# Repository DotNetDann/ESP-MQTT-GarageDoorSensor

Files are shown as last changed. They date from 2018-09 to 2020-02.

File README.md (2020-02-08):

# ESP8266 MQTT GarageDoorSensor and Temperture HomeAssistant
This project allows for up to  three "dumb" garage door openers to be controlled (open/close) and report garage door status (open/closed/occupied) via MQTT. In addition if you can also monitor the Temperture and Humidity within your garage to over MQTT as well.

The code covered in this repository utilizes [Home Assistant's MQTT Cover Component](https://www.home-assistant.io/components/cover.mqtt/) and uses an ESP8266 microcontroller. There is a sample configuration in the repository

Inspiration for this comes from GarHAge and OpenGarage. The Temp and Humidity code for a DHT22 from GarHage, and now it morphed to change to NewPing for the ultrasonic HC-SR04 due to the inconsitant reading using the Ultrasonic library with the HC-SCR04 I aquired from china.

**NOTE:** I am currrently only using this with one garage door, to enable for 2 or 3, just enable the use to true in the auth.h file you create

#### Supported Features Include
- Report status on up to 3 garage doors
- Report information on Temp and Humidity
- Ability to Select Celius or Fahrenheit for Temp
- Web page for status of Garage Doors and Temperature
- Events and status sent via MQTT
- MQTT commands to toggle relays to open/close the garage doors
- Over-the-Air (OTA) Upload from the ArduinoIDE!

#### OTA Uploading
This code also supports remote uploading to the ESP8266 using Arduino's OTA library. To utilize this, you'll need to first upload the sketch using the traditional USB method. However, if you need to update your code after that, your WIFI-connected ESP chip should show up as an option under Tools -> Port -> 'HostName'at your.ip.address.xxx. 

More information on OTA uploading can be found [here](http://esp8266.github.io/Arduino/versions/2.0.0/doc/ota_updates/ota_updates.html). 

#### Parts List
- [NodeMCU](https://www.amazon.com/HiLetgo-Version-NodeMCU-Internet-Development/dp/B010O1G1ES/)
- [1-3 x HC-SR04 Ultrasonic Sensors](https://au.element14.com/mcm/83-17989/hc-sr04-ultrasonic-sensor-for/dp/2801408?ost=HC-SR04) Depending on how many Doors you will monitor
- [5V 4 Channel Relay Board](https://www.ebay.com./sch/i.html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) If Controling 2 or More Garage Doors this is the best choice
- Otherwise buy a Single Relay for a singe Door
	[5V 1 Channel Relay Board](https://www.ebay.com./sch/i.html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)

#### Wiring Diagram
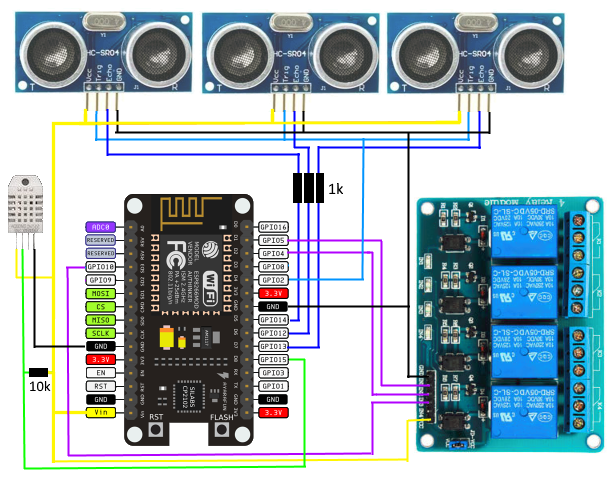
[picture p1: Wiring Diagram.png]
Wiring Diagram


#### Web page
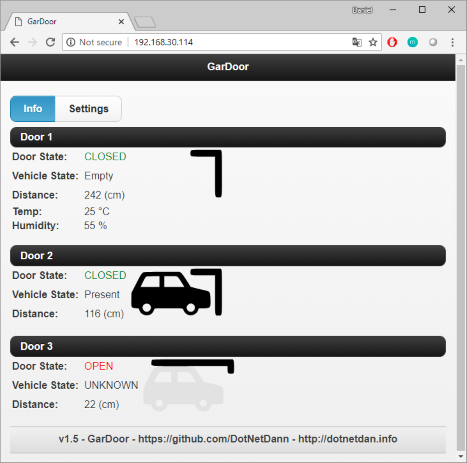
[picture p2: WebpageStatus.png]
Webpage Status


#### Completed Project
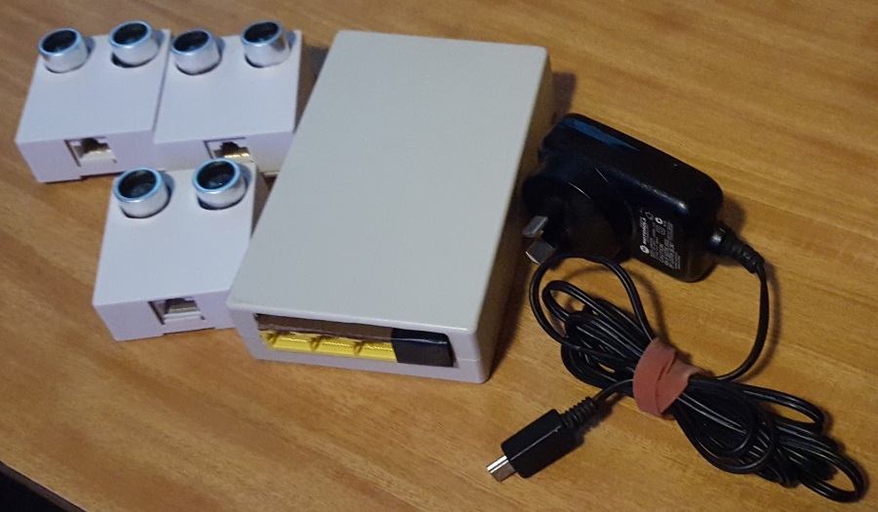
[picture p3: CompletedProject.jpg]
Completed Project

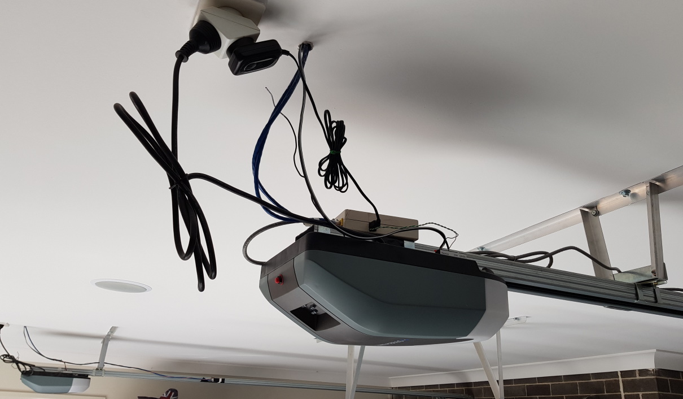
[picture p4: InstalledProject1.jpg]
Installed

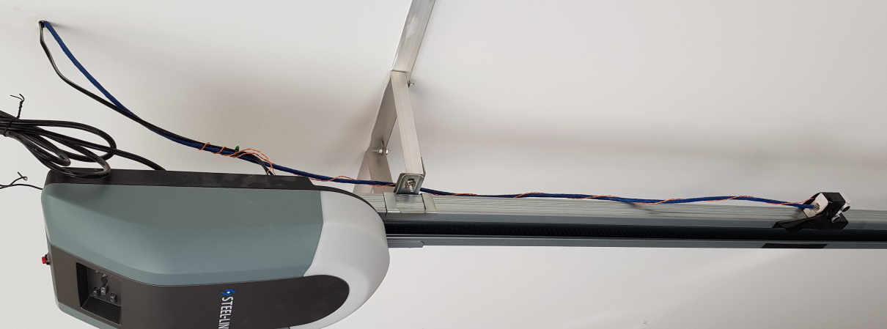
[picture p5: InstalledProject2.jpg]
Installed


I have also made a stl bracket to hold it to the rail 

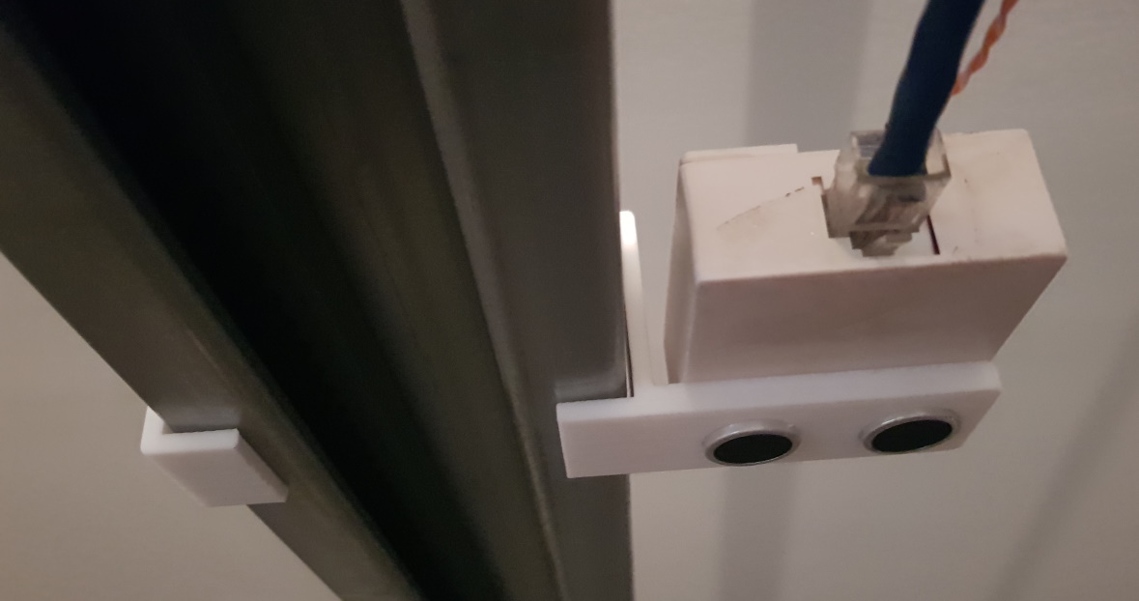
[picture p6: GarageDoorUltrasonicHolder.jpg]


#### Sample MQTT commands
Listen to MQTT commands
> mosquitto_sub -h 172.17.0.1 -t '#'

Open the second garage door
> mosquitto_pub -h 172.17.0.1 -t GarDoor/2/action -m "OPEN"

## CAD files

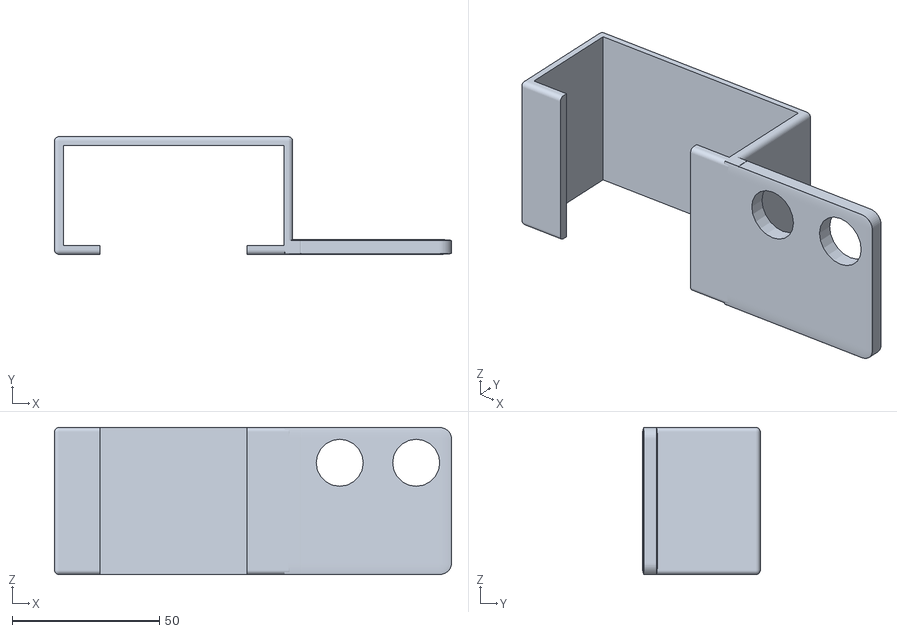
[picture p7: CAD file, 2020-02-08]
GarageDoorUltrasonicHolder.stl
135.0 x 40.0 x 50.0

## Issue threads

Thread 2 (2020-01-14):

Wiring Diagram

gdc2john, 2020-01-14:
HI Dan, I am setting up your controller but I notice that the wiring diagram does not line
up with the Auth.h file the outputs etc are different.
Are the correct one to use the ones in the auth.h file? which I guess must be correct

Cheer John

gdc2john, 2020-01-14:
I also get the an error when compiling the files in Arduinio IDE the eror is in web.h I have included a screen shot for your info
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

gdc2john, 2020-01-15:
Hi,, I solved the second problem, My Auth.h file must have had a corruption on download, a new download fixed it. Should have tried this before posting the error, sorry.

Closed 2020-01-19.

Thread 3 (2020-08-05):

I keep getting an error and cannot get this to work.

cbatten01, 2020-08-05:
I have tried everything and keep getting this error.  I think the codes were changed but the wiring diagram was not.  I am new to this.

ets Jan  8 2013,rst cause:4, boot mode:(3,6)

wdt reset
load 0x4010f000, len 3584, room 16
tail 0
chksum 0xb0
csum 0xb0
v5d3af165
~ld
Starting...

DotNetDann, 2020-08-06:
That message is your ESP chip resetting due to the code loop not running.
(Watch dog timer is resetting the board)
All pinouts are set by you in the auth.h file. Check these.
I would disable all but one garage door first and try that and then
re-enable others as you go.

I have actually moved off this and onto ESPHome
If you are starting out then this may be more friendly.

I have my config for esphome here -
https://github.com/DotNetDann/esphome-config/blob/master/garage_door.yaml

I hope that helps

Dan

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

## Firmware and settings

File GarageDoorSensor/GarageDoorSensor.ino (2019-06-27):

/*
  To use this code you will need the following dependencies:

  - Support for the ESP8266 boards.
        - You can add it to the board manager by going to File -> Preference and pasting http://arduino.esp8266.com/stable/package_esp8266com_index.json into the Additional Board Managers URL field.
        - Next, download the ESP8266 dependencies by going to Tools -> Board -> Board Manager and searching for ESP8266 and installing it.

  - You will also need to download the follow libraries by going to Sketch -> Include Libraries -> Manage Libraries
      - NewPing
      - PubSubClient
      - ArduinoJSON

  - Another like project https://hackaday.io/project/25090/instructions
  - Where this code was forked from https://github.com/DotNetDann/ESP-MQTT-GarageDoorSensor
*/

// 1.8 Change pins and small clean
// 1.7 Add ability to only close garage doors
// 1.6 Add diagnose infomation on distances
// 1.4 Changes to use NewPing
// 1.3 adds DHT Sensor for Temp and Humidty

// ------------------------------
// ---- all config in auth.h ----
// ------------------------------
#define VERSION F("v1.8 - GarDoor - https://github.com/DotNetDann - http://dotnetdan.info")

#include <ArduinoJson.h> // Benoit Blanchon
#include <ESP8266WiFi.h>
#include <ESP8266WebServer.h>
#include <ESP8266HTTPClient.h>
#include <PubSubClient.h> // Nick O'Leary
#include <NewPing.h> // Tim Eckel
#include <ArduinoOTA.h>
#include <DHT.h> // Adafruit
#include <Adafruit_Sensor.h> // Adafruit Unified Sensor
#include "auth.h"

#define DOOR_UNKNOWN         0x00
#define DOOR_OPENED          0x01
#define DOOR_CLOSEDNOCAR     0x02
#define DOOR_CLOSEDWITHCAR   0x03
#define SONAR_NUM 3      // Number of sensors.


/**************************************** GLOBALS ***************************************/
const int BUFFER_SIZE = JSON_OBJECT_SIZE(10);
#define MQTT_MAX_PACKET_SIZE 512

const int door_numValues = 10;
int door1_lastDistanceValues[door_numValues];
int door2_lastDistanceValues[door_numValues];
int door3_lastDistanceValues[door_numValues];
int door1_lastDistanceValue = 0;
int door2_lastDistanceValue = 0;
int door3_lastDistanceValue = 0;

char* birthMessage = "online";
const char* lwtMessage = "offline";

const unsigned long dht_publish_interval_s = DHT_PUBLISH_INTERVAL;
unsigned long dht_lastReadTime = -1000;

/******************************** GLOBAL OBJECTS *******************************/

NewPing sonar[SONAR_NUM] = {   // Sensor object array.
  NewPing(DOOR_TRIG_PIN, DOOR1_ECHO_PIN, ULTRASONIC_MAX_DISTANCE), // Each sensor's trigger pin, echo pin, and max distance to ping. 0-2
  NewPing(DOOR_TRIG_PIN, DOOR2_ECHO_PIN, ULTRASONIC_MAX_DISTANCE), 
  NewPing(DOOR_TRIG_PIN, DOOR3_ECHO_PIN, ULTRASONIC_MAX_DISTANCE)
};

WiFiClient espClient;
PubSubClient client(espClient);
ESP8266WebServer server(80);
DHT dht(DHT_PIN, DHT_TYPE);

// Get the state of the garage based upon the sensor distance
byte getState(int distance)
{
  if (distance <= 1) {
    return DOOR_UNKNOWN; // Should not ever be this close. Probably an error
  } else if (distance <= ULTRASONIC_DIST_MAX_OPEN) {
    return DOOR_OPENED;
  } else if (distance <= ULTRASONIC_DIST_MAX_CAR) {
    return DOOR_CLOSEDWITHCAR;
  } else {
    return DOOR_CLOSEDNOCAR;
  }
}

#include "web.h"

/********************************** START SETUP *****************************************/
void setup() {
  pinMode(LED_BUILTIN, OUTPUT);       // Initialize the LED_BUILTIN pin as an output (So it doesnt float as a LED is on this pin)
  digitalWrite(LED_BUILTIN, LOW);     // Turn the status LED on

  Serial.begin(115200);
  delay(10);
  Serial.println(F("Starting..."));

  // Setup Door 1 pins
  pinMode(DOOR1_RELAY_PIN, OUTPUT);
  digitalWrite(DOOR1_RELAY_PIN, HIGH);

  #if DOOR2_ENABLED == true
    pinMode(DOOR2_RELAY_PIN, OUTPUT);
    digitalWrite(DOOR2_RELAY_PIN, HIGH);
  #endif

  #if DOOR3_ENABLED == true
    pinMode(DOOR3_RELAY_PIN, OUTPUT);
    digitalWrite(DOOR3_RELAY_PIN, HIGH);
  #endif

  #if DHT_ENABLED == true
    dht.begin();
  #endif

  setup_wifi();

  client.setServer(MQTT_SERVER, MQTT_PORT);
  client.setCallback(callback);

  server.on("/", ServeWebClients);
  server.begin();

  //OTA SETUP
  ArduinoOTA.setPort(OTAport);
  ArduinoOTA.setHostname(WIFI_HOSTNAME); // Hostname defaults to esp8266-[ChipID]
  ArduinoOTA.setPassword((const char *)OTApassword); // No authentication by default

  ArduinoOTA.onStart([]() {
    Serial.println("Starting");
  });
  ArduinoOTA.onEnd([]() {
    Serial.println("\nEnd");
  });
  ArduinoOTA.onProgress([](unsigned int progress, unsigned int total) {
    Serial.printf("Progress: %u%%\r", (progress / (total / 100)));
  });
  ArduinoOTA.onError([](ota_error_t error) {
    Serial.printf("Error[%u]: ", error);
    if (error == OTA_AUTH_ERROR) Serial.println("Auth Failed");
    else if (error == OTA_BEGIN_ERROR) Serial.println("Begin Failed");
    else if (error == OTA_CONNECT_ERROR) Serial.println("Connect Failed");
    else if (error == OTA_RECEIVE_ERROR) Serial.println("Receive Failed");
    else if (error == OTA_END_ERROR) Serial.println("End Failed");
  });
  ArduinoOTA.begin();

  Serial.println(F("Ready"));
  digitalWrite(LED_BUILTIN, HIGH);     // Turn the status LED off
}


/********************************** START SETUP WIFI *****************************************/
void setup_wifi() {
  delay(10);
  Serial.print(F("Connecting to SSID: "));
  Serial.println(WIFI_SSID);

  // We start by connecting to a WiFi network
  WiFi.mode(WIFI_STA);
  //wifi_set_sleep_type(LIGHT_SLEEP_T); // Enable light sleep
  WiFi.hostname(WIFI_HOSTNAME);

  if (WiFi.status() != WL_CONNECTED) {  // FIX FOR USING 2.3.0 CORE (only .begin if not connected)
    WiFi.begin(WIFI_SSID, WIFI_PASSWORD);
  }

  while (WiFi.status() != WL_CONNECTED) {
    delay(500);
    Serial.print(F("."));
  }

  Serial.println(F(""));
  Serial.println(F("WiFi connected"));
  Serial.print(F("IP address: "));
  Serial.println(WiFi.localIP());
}


/********************************** START CALLBACK *****************************************/
void callback(char* topic, byte* payload, unsigned int length) {
  Serial.println(F(""));
  Serial.print(F("Message arrived ["));
  Serial.print(topic);
  Serial.print(F("] "));

  for (int i = 0; i < length; i++) {
    Serial.print((char)payload[i]);
  }
  Serial.println();

  String topicToProcess = topic;
  payload[length] = '\0';
  String payloadToProcess = (char*)payload;

  // Action Command
  if (payloadToProcess == "OPEN") {
    Serial.print(F("Triggering OPEN relay!"));

    if (topicToProcess == MQTT_DOOR1_ACTION_TOPIC && // Door 1
         (getState(door1_lastDistanceValue) == DOOR_CLOSEDNOCAR || getState(door1_lastDistanceValue) == DOOR_CLOSEDWITHCAR) && // Garage is currently closed
         door1_lastDistanceValues[0] > 0 && // Last value was valid (Known state)
         !DOOR1_LIMIT_RELAY_CLOSE) { // We are not limiting the open command
      toggleRelay(DOOR1_RELAY_PIN);
      Serial.print(F("Door1 relay OPEN!"));
      
    } else if (topicToProcess == MQTT_DOOR2_ACTION_TOPIC && // Door 2
         (getState(door2_lastDistanceValue) == DOOR_CLOSEDNOCAR || getState(door2_lastDistanceValue) == DOOR_CLOSEDWITHCAR) && // Garage is currently closed
         door2_lastDistanceValues[0] > 0 && // Last value was valid (Known state)
         !DOOR2_LIMIT_RELAY_CLOSE) { // We are not limiting the open command
      toggleRelay(DOOR2_RELAY_PIN);
      Serial.print(F("Door2 relay OPEN!"));
      
    } else if (topicToProcess == MQTT_DOOR3_ACTION_TOPIC && // Door 3
         (getState(door3_lastDistanceValue) == DOOR_CLOSEDNOCAR || getState(door3_lastDistanceValue) == DOOR_CLOSEDWITHCAR) && // Garage is currently closed
         door3_lastDistanceValues[0] > 0 && // Last value was valid (Known state)
         !DOOR3_LIMIT_RELAY_CLOSE) { // We are not limiting the open command
      toggleRelay(DOOR3_RELAY_PIN);
      Serial.print(F("Door3 relay OPEN!"));

    } else {
      Serial.print(F("criteria not meet!"));
    }
    
    Serial.println(" -> DONE");
  }
  else if (payloadToProcess == "CLOSE") {
    Serial.print(F("Triggering CLOSE relay!"));
    
    if (topicToProcess == MQTT_DOOR1_ACTION_TOPIC && 
         getState(door1_lastDistanceValue) == DOOR_OPENED &&  // Garage is currently OPEN
         door1_lastDistanceValues[0] > 0) { // Last value was valid (Known state)
      toggleRelay(DOOR1_RELAY_PIN);
      Serial.print(F("Door1 relay CLOSED!"));

    } else if (topicToProcess == MQTT_DOOR2_ACTION_TOPIC && 
         getState(door2_lastDistanceValue) == DOOR_OPENED &&  // Garage is currently OPEN
         door2_lastDistanceValues[0] > 0) { // Last value was valid (Known state)
      toggleRelay(DOOR2_RELAY_PIN);
      Serial.print(F("Door2 relay CLOSED!"));

    } else if (topicToProcess == MQTT_DOOR3_ACTION_TOPIC && 
         getState(door3_lastDistanceValue) == DOOR_OPENED &&  // Garage is currently OPEN
         door3_lastDistanceValues[0] > 0) { // Last value was valid (Known state)
      toggleRelay(DOOR3_RELAY_PIN);
      Serial.print(F("Door3 relay CLOSED!"));

    } else {
      Serial.print(F("criteria not meet!"));
    }

    Serial.println(F(" -> DONE"));
  }
  else if (payloadToProcess == "STATE") {
    Serial.print(F("Publishing on-demand status update!"));
    Publish(MQTT_AVAIL_TOPIC, birthMessage);
    if (topicToProcess == MQTT_DOOR1_ACTION_TOPIC) {
      sendState(1);
    } else if (topicToProcess == MQTT_DOOR2_ACTION_TOPIC) {
      sendState(2);
    } else if (topicToProcess == MQTT_DOOR3_ACTION_TOPIC) {
      sendState(3);
    }
    Serial.println(F(" -> DONE"));
  }
  else if (payloadToProcess == "STOP") {
    Serial.print(F("We don’t know status of door while moving!"));
  } else {
    Serial.println(F("Unknown command!"));
  }
}


/********************************** START SEND STATE *****************************************/
void sendState(int door) {
  //{"state":"open","occupied":unknown,"distance":12,"name":"Door 1"}
  //{"state":"closed","occupied":true,"distance":1000,"name":"Door 2"}
  //{"state":"closed","occupied":false,"distance":2350,"name":"Door 3"}

  StaticJsonBuffer<BUFFER_SIZE> jsonBuffer;
  JsonObject& root = jsonBuffer.createObject();

  byte state = DOOR_UNKNOWN;
  char* topic = "";
  if (door == 1) {
    state = getState(door1_lastDistanceValue);
    topic = MQTT_DOOR1_STATUS_TOPIC;
    root["name"] = DOOR1_ALIAS;
    root["distance"] = door1_lastDistanceValue;
  } else if (door == 2) {
    state = getState(door2_lastDistanceValue);
    topic = MQTT_DOOR2_STATUS_TOPIC;
    root["name"] = DOOR2_ALIAS;
    root["distance"] = door2_lastDistanceValue;
  } else if (door == 3) {
    state = getState(door3_lastDistanceValue);
    topic = MQTT_DOOR3_STATUS_TOPIC;
    root["name"] = DOOR3_ALIAS;
    root["distance"] = door3_lastDistanceValue;
  } else {
    return;
  }

  char* doorState = "unknown";
  char* occupiedState = "unknown";
  if (state == DOOR_OPENED) {
    doorState = "open";
  } else if (state == DOOR_CLOSEDNOCAR) {
    doorState = "closed";
    occupiedState = "false";
  } else if (state == DOOR_CLOSEDWITHCAR) {
    doorState = "closed";
    occupiedState = "true";
  }
  root["state"] = doorState;
  root["occupied"] = occupiedState;

  char buffer[root.measureLength() + 1];
  root.printTo(buffer, sizeof(buffer));

  Publish(topic, buffer);

  // For HA. Cannot read JSON so send a simple state result also
  char* extraTopicState = "/value";
  char extraTopic[100];
  snprintf(extraTopic, sizeof extraTopic, "%s%s", topic, extraTopicState);
  Publish(extraTopic, doorState);
}

void Publish(char* topic, char* message) {
  client.publish(topic, message, true);

  //Print what was sent to console
  Serial.println(F(""));
  Serial.print(F("Published ["));
  Serial.print(topic);
  Serial.print(F("] "));
  Serial.println(message);
}

/********************************** START RELAY *****************************************/
void toggleRelay(int pin) {
    digitalWrite(pin, LOW);
    delay(RELAY_ACTIVE_TIMEOUT);
    digitalWrite(pin, HIGH);
}


/********************************** START RECONNECT *****************************************/
void reconnect() {
  // Loop until we're reconnected
  while (!client.connected()) {
    Serial.print(F("Attempting MQTT connection..."));
    // Attempt to connect
    if (client.connect(WIFI_HOSTNAME, MQTT_USER, MQTT_PASSWORD, MQTT_AVAIL_TOPIC, 0, true, lwtMessage)) {
      Serial.println(F("connected"));

      // Publish the birth message on connect/reconnect
      Publish(MQTT_AVAIL_TOPIC, birthMessage);

      // Subscribe to the action topics to listen for action messages
      Serial.print(F("Subscribing to "));
      Serial.print(MQTT_DOOR1_ACTION_TOPIC);
      Serial.println(F("..."));
      client.subscribe(MQTT_DOOR1_ACTION_TOPIC);

      
      #if DOOR2_ENABLED == true
        Serial.print(F("Subscribing to "));
        Serial.print(MQTT_DOOR2_ACTION_TOPIC);
        Serial.println(F("..."));
        client.subscribe(MQTT_DOOR2_ACTION_TOPIC);
      #endif

      #if DOOR3_ENABLED == true
        Serial.print(F("Subscribing to "));
        Serial.print(MQTT_DOOR3_ACTION_TOPIC);
        Serial.println(F("..."));
        client.subscribe(MQTT_DOOR3_ACTION_TOPIC);
      #endif

      // Publish the current door status on connect/reconnect to ensure status is synced with whatever happened while disconnected
      door1_lastDistanceValue = 0;
      door2_lastDistanceValue = 0;
      door3_lastDistanceValue = 0;
      check_door_status();
       
    } else {
      Serial.print(F("failed, rc="));
      Serial.print(client.state());
      Serial.println(F(" try again in 5 seconds"));
      // Wait 5 seconds before retrying
      delay(5000);
    }
  }
}


/********************************** START DOOR STATUS *****************************************/
void check_door_status() {
  byte state;
  byte stateVerify;
  int distance = 0;
  int lastDistance = 0;

  // ---- Door 1 ----
  distance = sonar[0].ping_cm(); // Take a reading
  Serial.print(distance);
  Serial.print(".");

  memmove(&door1_lastDistanceValues[1], &door1_lastDistanceValues[0], (door_numValues - 1) * sizeof(door1_lastDistanceValues[0])); // Move the array forward
  door1_lastDistanceValues[0] = distance;

  // Find the previous distance that was valid
  lastDistance = 0;
  for (int y=1; y<door_numValues; y++) {
    if (door1_lastDistanceValues[y] > 0) {
      lastDistance = door1_lastDistanceValues[y];
      break;
    }
  }

  if ((distance > 0) && (lastDistance > 0)) {
    state = getState(distance);
    stateVerify = getState(lastDistance);
    
    if ((state == stateVerify) && (state != getState(door1_lastDistanceValue))) {
      digitalWrite(LED_BUILTIN, LOW);     // Turn the status LED on
      door1_lastDistanceValue = distance;
      sendState(1);
      digitalWrite(LED_BUILTIN, HIGH);     // Turn the status LED off
    }
  }


  // ---- Door 2 ----
  #if DOOR2_ENABLED == true
    delay(ULTRASONIC_SETTLE_TIMEOUT); // Let the last ping settle
    distance = sonar[1].ping_cm(); // Take a reading
    Serial.print(distance);
    Serial.print(".");

    memmove(&door2_lastDistanceValues[1], &door2_lastDistanceValues[0], (door_numValues - 1) * sizeof(door2_lastDistanceValues[0])); // Move the array forward
    door2_lastDistanceValues[0] = distance;
  
    // Find the previous distance that was valid
    lastDistance = 0;
    for (int y=1; y<door_numValues; y++) {
      if (door2_lastDistanceValues[y] > 0) {
        lastDistance = door2_lastDistanceValues[y];
        break;
      }
    }
  
    if ((distance > 0) && (lastDistance > 0)) {
      state = getState(distance);
      stateVerify = getState(lastDistance);
      
      if ((state == stateVerify) && (state != getState(door2_lastDistanceValue))) {
        digitalWrite(LED_BUILTIN, LOW);     // Turn the status LED on
        door2_lastDistanceValue = distance;
        sendState(2);
        digitalWrite(LED_BUILTIN, HIGH);     // Turn the status LED off
      }
    }
  #endif


  // ---- Door 3 ----
  #if DOOR3_ENABLED == true
    delay(ULTRASONIC_SETTLE_TIMEOUT); // Let the last ping settle
    distance = sonar[2].ping_cm(); // Take a reading
    Serial.print(distance);
    Serial.print(".");

    memmove(&door3_lastDistanceValues[1], &door3_lastDistanceValues[0], (door_numValues - 1) * sizeof(door3_lastDistanceValues[0])); // Move the array forward
    door3_lastDistanceValues[0] = distance;
  
    // Find the previous distance that was valid
    lastDistance = 0;
    for (int y=1; y<door_numValues; y++) {
      if (door3_lastDistanceValues[y] > 0) {
        lastDistance = door3_lastDistanceValues[y];
        break;
      }
    }
  
    if ((distance > 0) && (lastDistance > 0)) {
      state = getState(distance);
      stateVerify = getState(lastDistance);
      
      if ((state == stateVerify) && (state != getState(door3_lastDistanceValue))) {
        digitalWrite(LED_BUILTIN, LOW);     // Turn the status LED on
        door3_lastDistanceValue = distance;
        sendState(3);
        digitalWrite(LED_BUILTIN, HIGH);     // Turn the status LED off
      }
    }
  #endif

  Serial.println(".");
}

/*************************************DHT SENSOR*********************************************/


void dht_read_publish() {
  // Read values from sensor
  float hum = dht.readHumidity();
  float tempRaw = dht.readTemperature();

  // Check if there was an error reading values
  if (isnan(hum) || isnan(tempRaw)) {
    Serial.print("Failed to read from DHT sensor; will try again in ");
    Serial.print(dht_publish_interval_s);
    Serial.println(" seconds...");
    return;
  }

  boolean celsius = DHT_TEMPERATURE_CELSIUS;
  float temp;
  if (celsius) {
    temp = tempRaw;
  } else {
    temp = (tempRaw * 1.8 + 32);
  }

  // Publish the temperature and humidity payloads via MQTT
  char payload[4];
  dtostrf(temp, 4, 0, payload);
  Publish(MQTT_TEMPERATURE_TOPIC, payload);

  dtostrf(hum, 4, 0, payload);
  Publish(MQTT_HUMIDITY_TOPIC, payload); 
}


/********************************** START MAIN LOOP *****************************************/
void loop() {

  if (!client.connected()) {
    reconnect();
  }

  unsigned long currentTime = millis();
  
  if (WiFi.status() != WL_CONNECTED) {
    delay(1);
    Serial.print(F("WIFI Disconnected. Attempting reconnection."));
    setup_wifi();
    return;
  }

  client.loop(); // Check MQTT

  ArduinoOTA.handle(); // Check OTA Firmware Updates

  server.handleClient(); // Check Web page requests

  check_door_status(); // Check the sensors and publish any changes
  
  #if DHT_ENABLED == true
    if (currentTime - dht_lastReadTime > (dht_publish_interval_s * 1000)) {
      dht_read_publish();
      dht_lastReadTime = millis();
    }
  #endif
   
  //delay(500); // We have enabled Light sleep so this delay should reduce the power used
  delay(800); // We have enabled Light sleep so this delay should reduce the power used
  //delay(2000); // We have enabled Light sleep so this delay should reduce the power used
  //Serial.print(".");
}

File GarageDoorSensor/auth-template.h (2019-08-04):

/* Add your keys & rename this file to auth.h */

#ifndef _AUTH_DETAILS
#define _AUTH_DETAILS

// Wifi Settings
#define WIFI_HOSTNAME "GarDoor"
#define WIFI_SSID "ssid"
#define WIFI_PASSWORD "password"

// MQTT Settings
#define MQTT_SERVER "mqtt server ip"
#define MQTT_USER ""
#define MQTT_PASSWORD ""
#define MQTT_PORT 1883
#define MQTT_AVAIL_TOPIC WIFI_HOSTNAME "/availability"

// OTA Settings for pushing updated software
#define OTApassword "ota password" //the password you will need to enter to upload remotely via the ArduinoIDE
#define OTAport 8266

// Distance Parameters
#define ULTRASONIC_MAX_DISTANCE 400 // Maximum distance (in cm) to ping.
#define ULTRASONIC_DIST_MAX_OPEN 70 // cm
#define ULTRASONIC_DIST_MAX_CAR 120 // cm
#define ULTRASONIC_SETTLE_TIMEOUT 500 // ms to wait between pings (as all sensors get triggered at the same time)
#define RELAY_ACTIVE_TIMEOUT 500 // ms the time the relay will close to actuate the door opener
#define DOOR_TRIG_PIN 14 // D4 on ESP8266

// Door 1 Parameters
#define DOOR1_ALIAS "Door 1"
#define MQTT_DOOR1_ACTION_TOPIC WIFI_HOSTNAME "/1/action"
#define MQTT_DOOR1_STATUS_TOPIC WIFI_HOSTNAME "/1/status"
#define DOOR1_RELAY_PIN 10 // SD3 on ESP8266
#define DOOR1_ECHO_PIN 4 // D2 on ESP8266
#define DOOR1_LIMIT_RELAY_CLOSE false

// Door 2 Parameters
#define DOOR2_ENABLED true
#define DOOR2_ALIAS "Door 2"
#define MQTT_DOOR2_ACTION_TOPIC WIFI_HOSTNAME "/2/action"
#define MQTT_DOOR2_STATUS_TOPIC WIFI_HOSTNAME "/2/status"
#define DOOR2_RELAY_PIN 3 // RX on ESP8266
#define DOOR2_ECHO_PIN 5 // D1 on ESP8266
#define DOOR2_LIMIT_RELAY_CLOSE false

// Door 3 Parameters
#define DOOR3_ENABLED true
#define DOOR3_ALIAS "Door 3"
#define MQTT_DOOR3_ACTION_TOPIC WIFI_HOSTNAME "/3/action"
#define MQTT_DOOR3_STATUS_TOPIC WIFI_HOSTNAME "/3/status"
#define DOOR3_RELAY_PIN 12 // D6 on ESP8266
#define DOOR3_ECHO_PIN 0 // D3 on ESP8266
#define DOOR3_LIMIT_RELAY_CLOSE false

// DHT Parameters
#define DHT_ENABLED false
#define DHT_PIN 13 // D7 on ESP8266
#define DHT_TYPE DHT22 // or: DHT21 or DHT22
#define MQTT_TEMPERATURE_TOPIC WIFI_HOSTNAME "/temperature"
#define MQTT_HUMIDITY_TOPIC WIFI_HOSTNAME "/humidity"
#define DHT_PUBLISH_INTERVAL 300
#define DHT_TEMPERATURE_CELSIUS true
#define DHT_TEMPERATURE_ALIAS "Temperature"
#define DHT_HUMIDITY_ALIAS "Humidity"

#endif

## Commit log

2018-04-19 First Push - Not tested
    Im waiting for the sensors but should work. :)
2018-09-21 Added a DHT Sensor to Monitor Temp & Hum, Changed to PingNew (#1)
    * Add DHT Variables for monitoring Temp and Hunmidity
    * Add DHT Sensor
    * Add DHT Temp and Humidty
    * Add DHT
    * Add Temp and Humidity from DHT to Web
    * Update Temp and Humidity o Web Pge
    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
2019-05-12 Debugging and Close Only
    Add some debugging information as some sensors are being troublesome. I also now have the option to prevent opening the doors. So you cannot gain access via MQTT in case you get hacked.
    [GarageDoorSensor.ino, auth-template.h]
2020-02-08 Added a STL bracket to hold sensor to rail
    [GarageDoorUltrasonicHolder.stl]
